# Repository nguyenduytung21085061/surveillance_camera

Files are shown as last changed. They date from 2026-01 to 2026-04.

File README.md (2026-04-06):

# 📷 Smart Home Surveillance Camera System

🇺🇸 English | 🇻🇳 [Vietnamese](README_vi.md)

---

## 📌 Project Status

This project is currently in the **research and development stage**.  
The goal is to develop a real product for **home use**, testing system stability, performance, and usability in real-world conditions.

---

## 🎯 Project Goal

Build a **low-cost smart home surveillance system** that can:

- Detect when someone stands in front of the house gate
- Notify family members inside the house in real time
- Run AI detection on an embedded device

In addition, the Camera Node is designed so it can be developed into an **independent smart door camera product**, which can:

- Be mounted in front of an apartment or house door
- Monitor visitors in real time
- Recognize whether the person is a family member or just detect unknown people
- Work as a standalone smart security device

---

## 🧱 System Architecture

The system is divided into **two main nodes**:

System Overview

---

## 1️⃣ Camera Node

Main task: Monitor the front gate and detect people.

### Hardware

- Embedded board: Luckfox Pico (RV1103G1)
- USB Camera
- USB WiFi dongle (mainly for SSH development)
- Real-time display screen

### Why Luckfox Pico?

- Powerful enough to run person detection models
- Small size, low power
- Suitable for edge AI applications

### Functions

- Capture video from USB camera
- Run AI model to detect people
- Display real-time video
- Send notification signal to Notice Node

---

## 2️⃣ Notice Node

Main task: Notify people inside the house.

### Hardware

- MCU: STM32F103RCT6
- Audio amplifier (I2S output)
- Speaker module
- Wireless communication module: HC-12

### Functions

- Receive signal from Camera Node
- Play voice/audio alert
- Can be placed in kitchen, bedroom, etc.

---

## 📡 Communication

Camera Node communicates with Notice Node using:

- HC-12 wireless serial module
- Low cost
- Long range
- Simple UART interface

---

## 🛠 Technologies Used

- Embedded Linux on Luckfox Pico
- STM32 HAL firmware (C language)
- UART wireless communication
- AI person detection model (YOLO / RKNN planned)

---

## 📅 Project Progress

| No | Task | Status | Completion Date |
|----|---|---|---|
| 1 | Read USB WiFi | ✅ Done | 24/01/2026 |
| 2 | Interface TFT display | ✅ Done | 25/01/2026 |
| 3 | Read USB camera | ✅ Done | 26/01/2026 |
| 4 | Stream USB camera on TFT | ✅ Done | 28/01/2026 |
| 5 | Add Mobile OpenCV on Luckfox Pico | ✅ Done | 29/01/2026 |
| 6 | Fit stream size from 160x120 → 160x128 on TFT | ✅ Done | 29/01/2026 |
| 7 | Run RKNN on Luckfox Pico | ✅ Done | 05/02/2026 |
| 8 | Load YOLOv5 model to detect person | ✅ Done | 07/02/2026 |
| 9 | Add confidence score on TFT | ✅ Done | 08/01/2026 |
|10 | Research USB hub expansion for Luckfox Pico | ✅ Done | 11/01/2026 |
|11 | Draw USB hub schematic for Camera Node | ✅ Done | 06/04/2026 |
|12 | Design PCB for Camera Node | ⏳ Pending | — |
|13 | Test STM32F103RCT6 board | ✅ Done | 15/01/2026 |
|14 | Test HC-12 communication between Luckfox Pico and STM32F103RCT6 | ✅ Done | 17/01/2026 |
|15 | Develop I2S audio with amplifier & speaker | ✅ Done| 22/02/2026 |
|16 | Full test: Person detection → Notice Node → Speaker alert | ⏳ Pending | — |
|17 | Research schematic for Notice Node | ⏳ Pending | — |
|18 | System evaluation testing | ⏳ Pending | — |
|19 | Upgrade TFT screen to larger display | ✅ Done | 03/04/2026 |
|20 | Research face embedding on Luckfox Pico | ⏳ Pending | — |
|21 | Develop standalone Camera Node product | ⏳ Pending | — |
|22 | Research mobile monitoring communication system | ⏳ Pending | — |

---

## 👨‍💻 Author

Nguyễn Duy Tùng  
Embedded Systems & IoT Developer  

---

⭐ If you like this project, please give it a star!

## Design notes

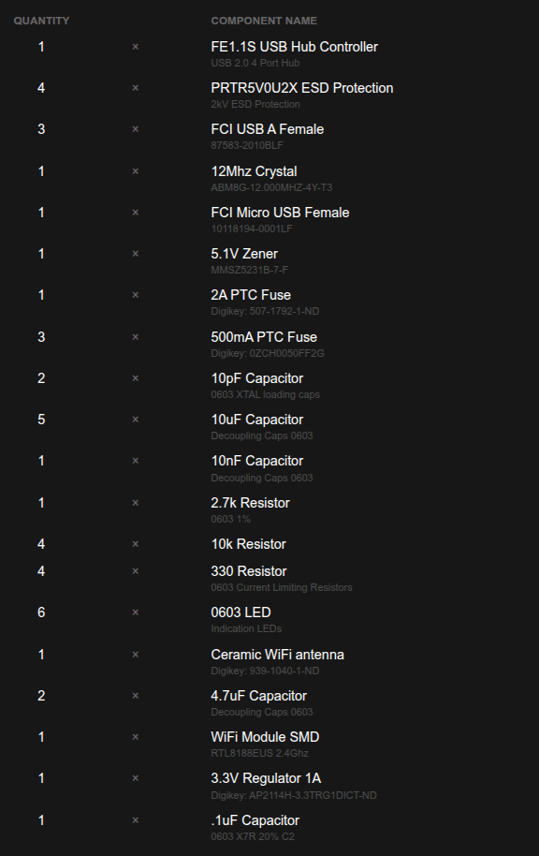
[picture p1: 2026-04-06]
schematics/doc/Screenshot from 2026-04-05 21-27-36.png

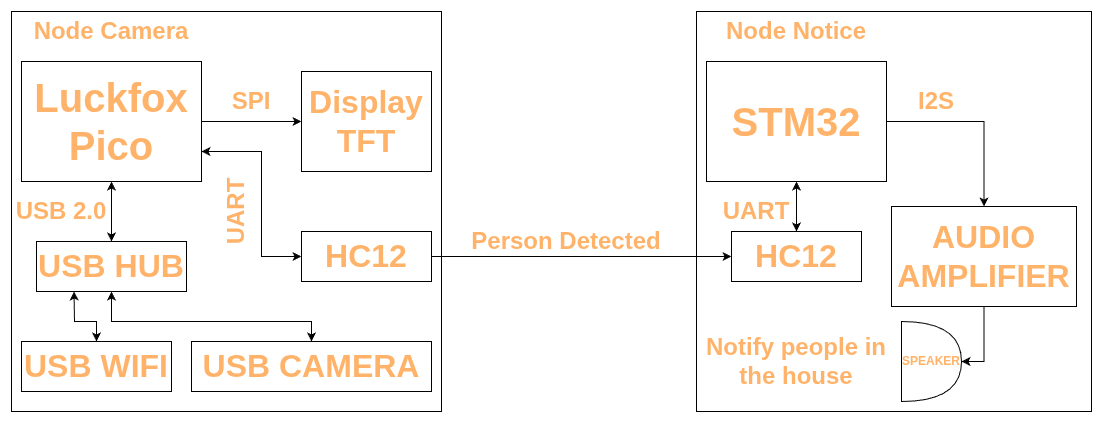
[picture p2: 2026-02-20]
photo/details_system.png

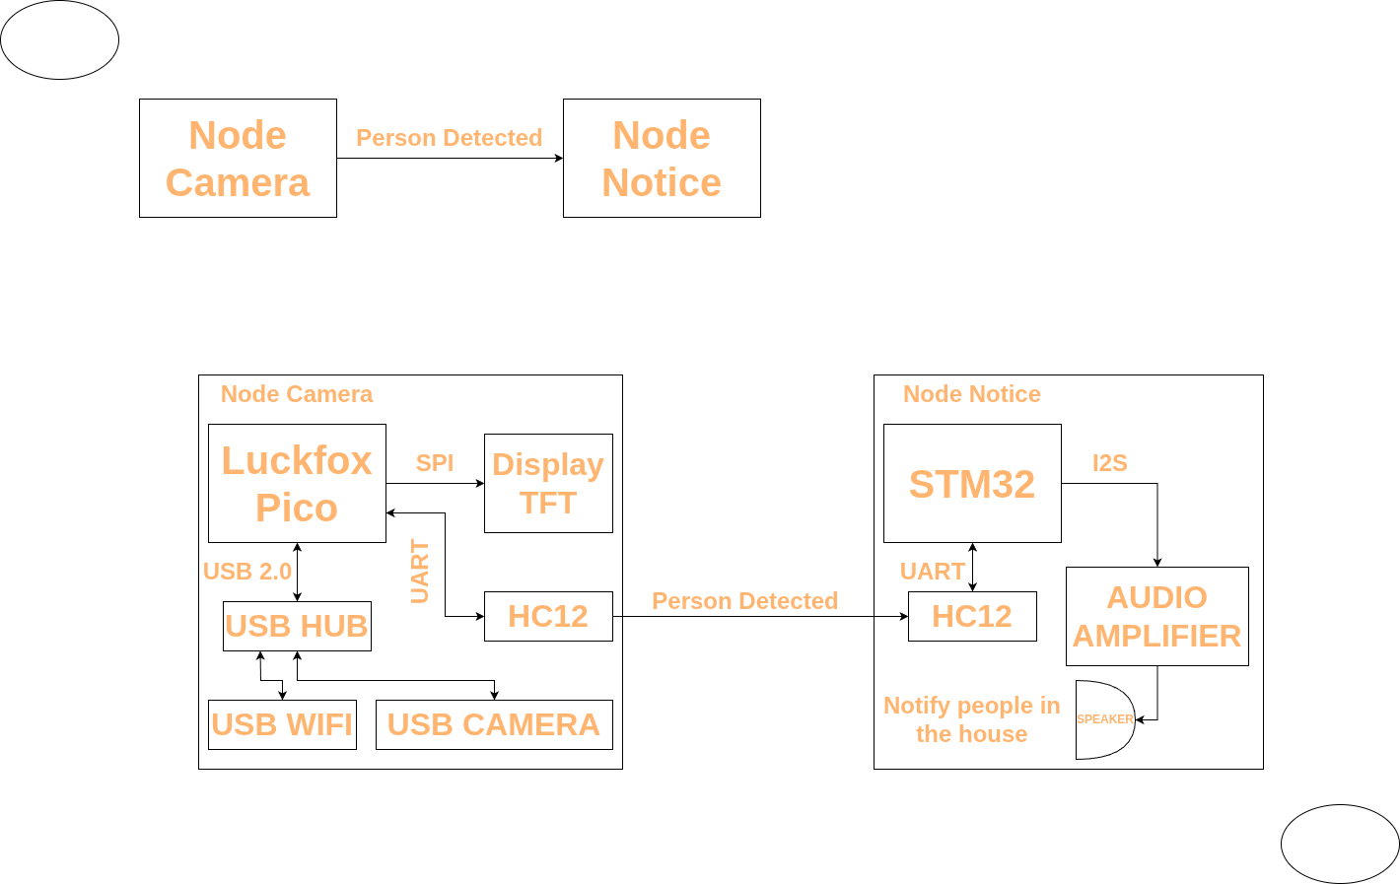
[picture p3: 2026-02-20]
diagram/system.png

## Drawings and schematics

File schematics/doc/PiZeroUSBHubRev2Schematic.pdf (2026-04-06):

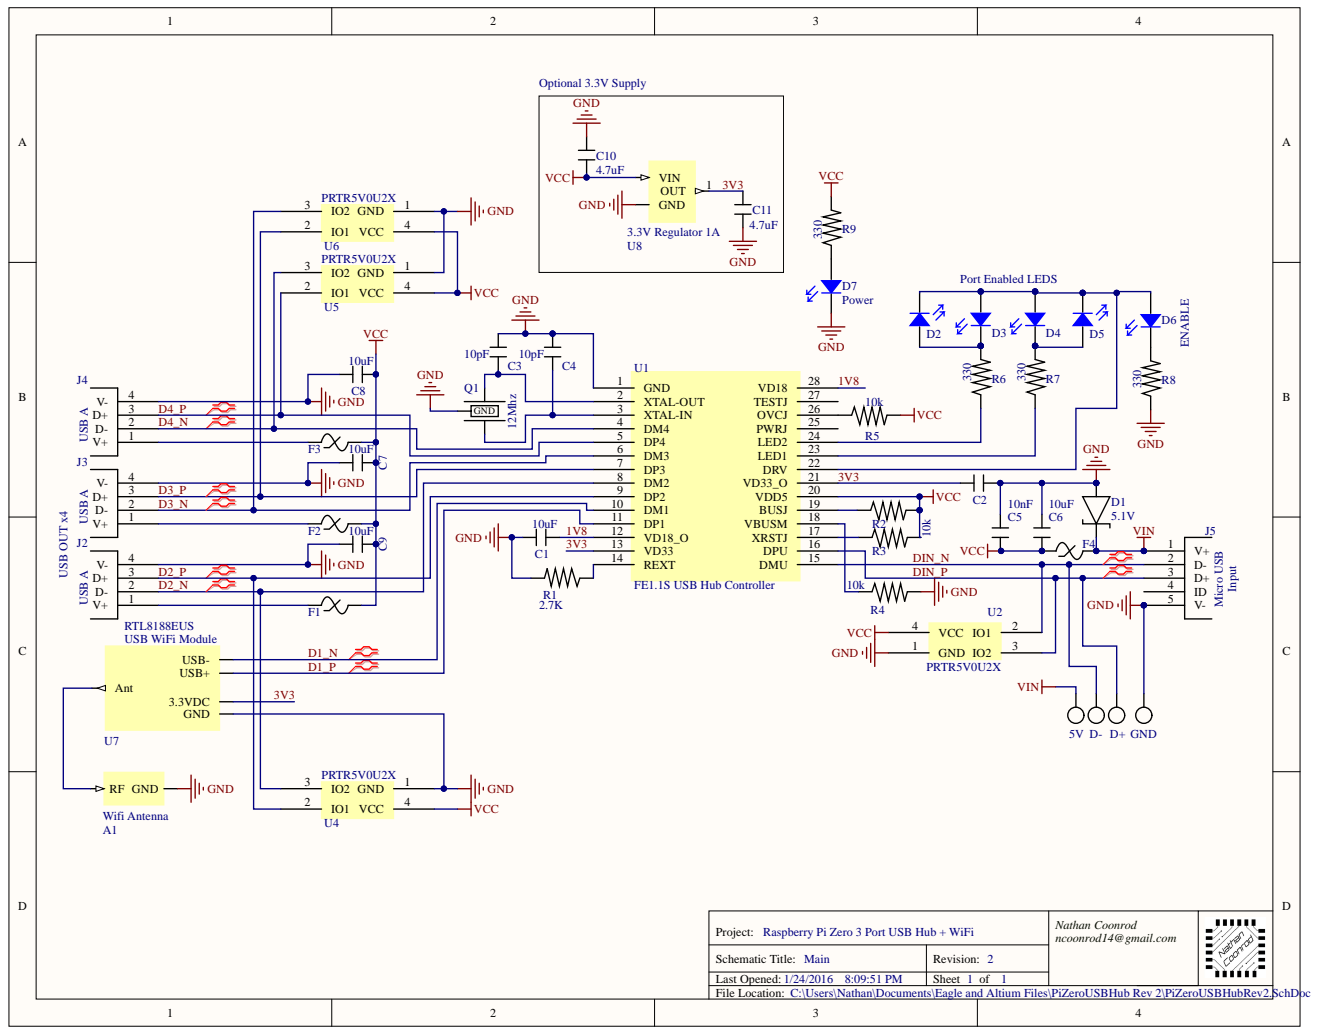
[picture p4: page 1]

Project: Raspberry Pi Zero 3 Port USB Hub + WiFi | Nathan Coonrod ncoonrod14@gmail.com

Schematic Title: Main | Revision: 2
Last Opened: 1/24/2016 8:09:51 PM | Sheet 1 of 1

C:\Users\Nathan\Documents\Eagle and Altium Files\PiZeroUSBHub Rev 2\PiZeroUSBHubRev2.SchDoc

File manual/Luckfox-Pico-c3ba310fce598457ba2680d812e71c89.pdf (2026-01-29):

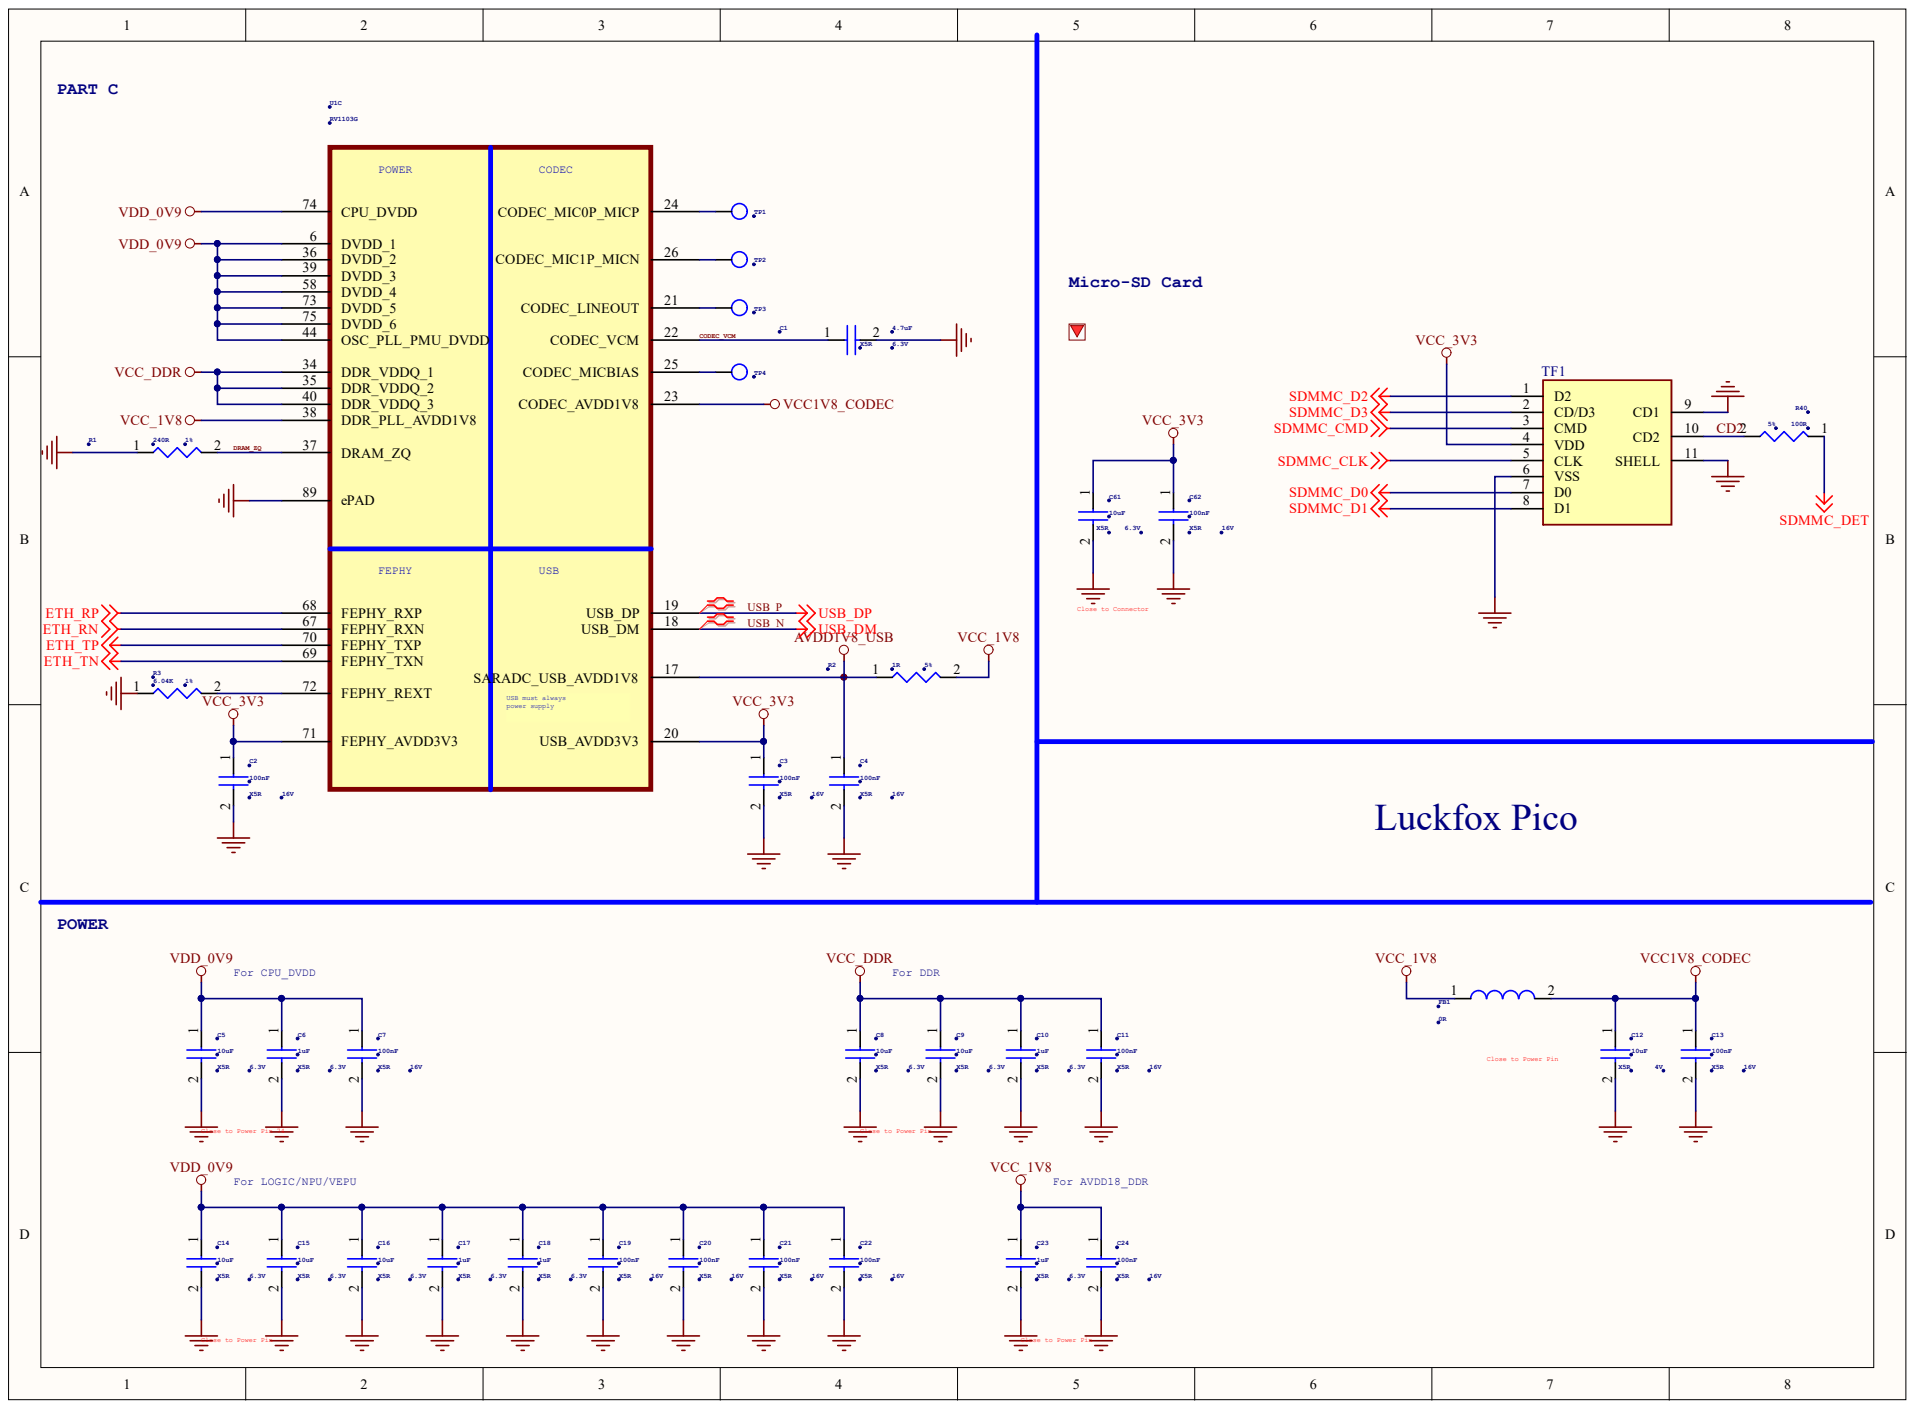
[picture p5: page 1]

Close to Power Pin

Close to Power Pin 74

For LOGIC/NPU/VEPU

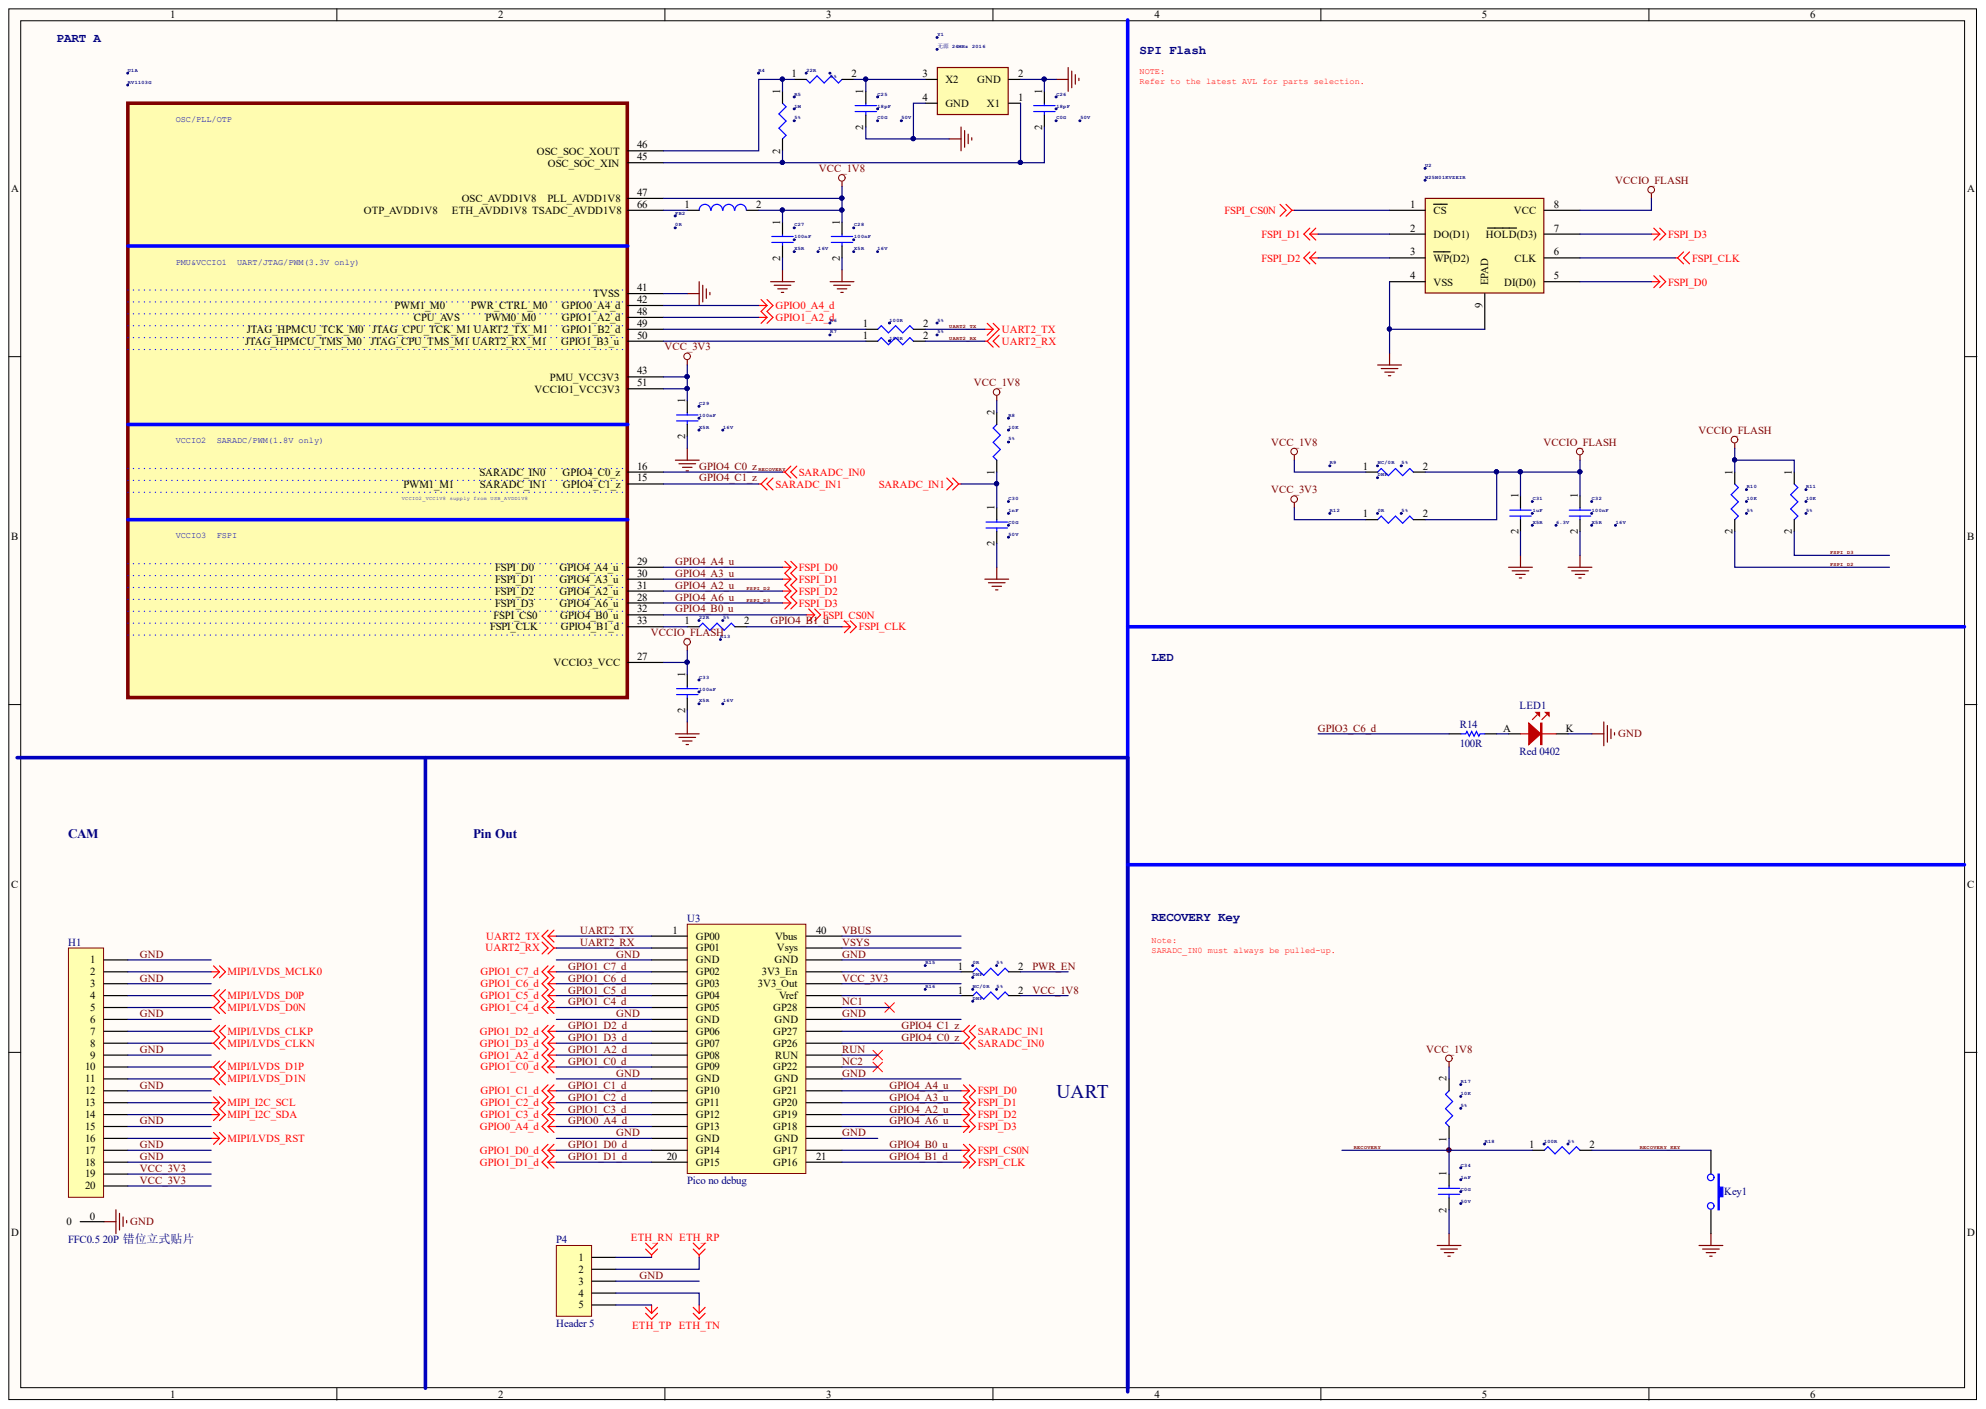
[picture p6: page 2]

NOTE:
Refer to the latest AVL for parts selection.

Note:
SARADC_IN0 must always be pulled-up.

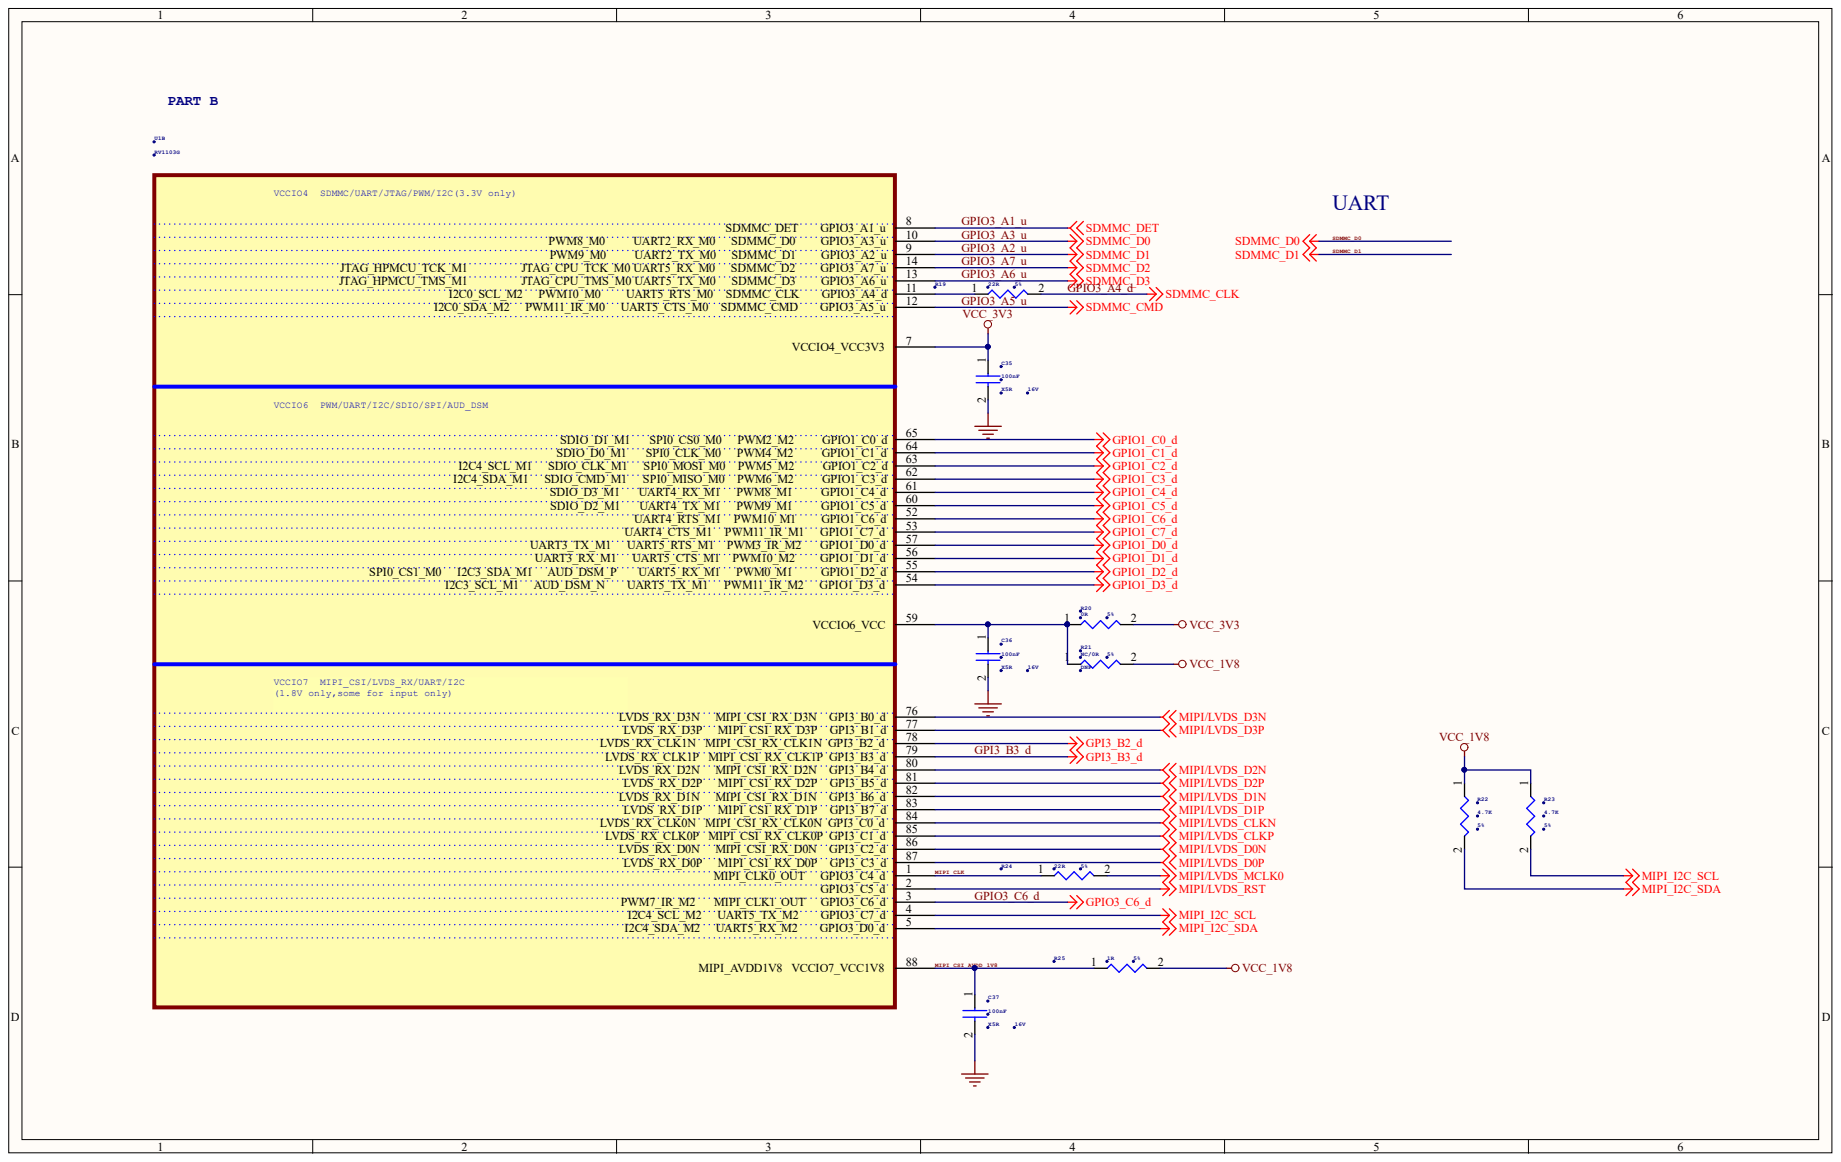
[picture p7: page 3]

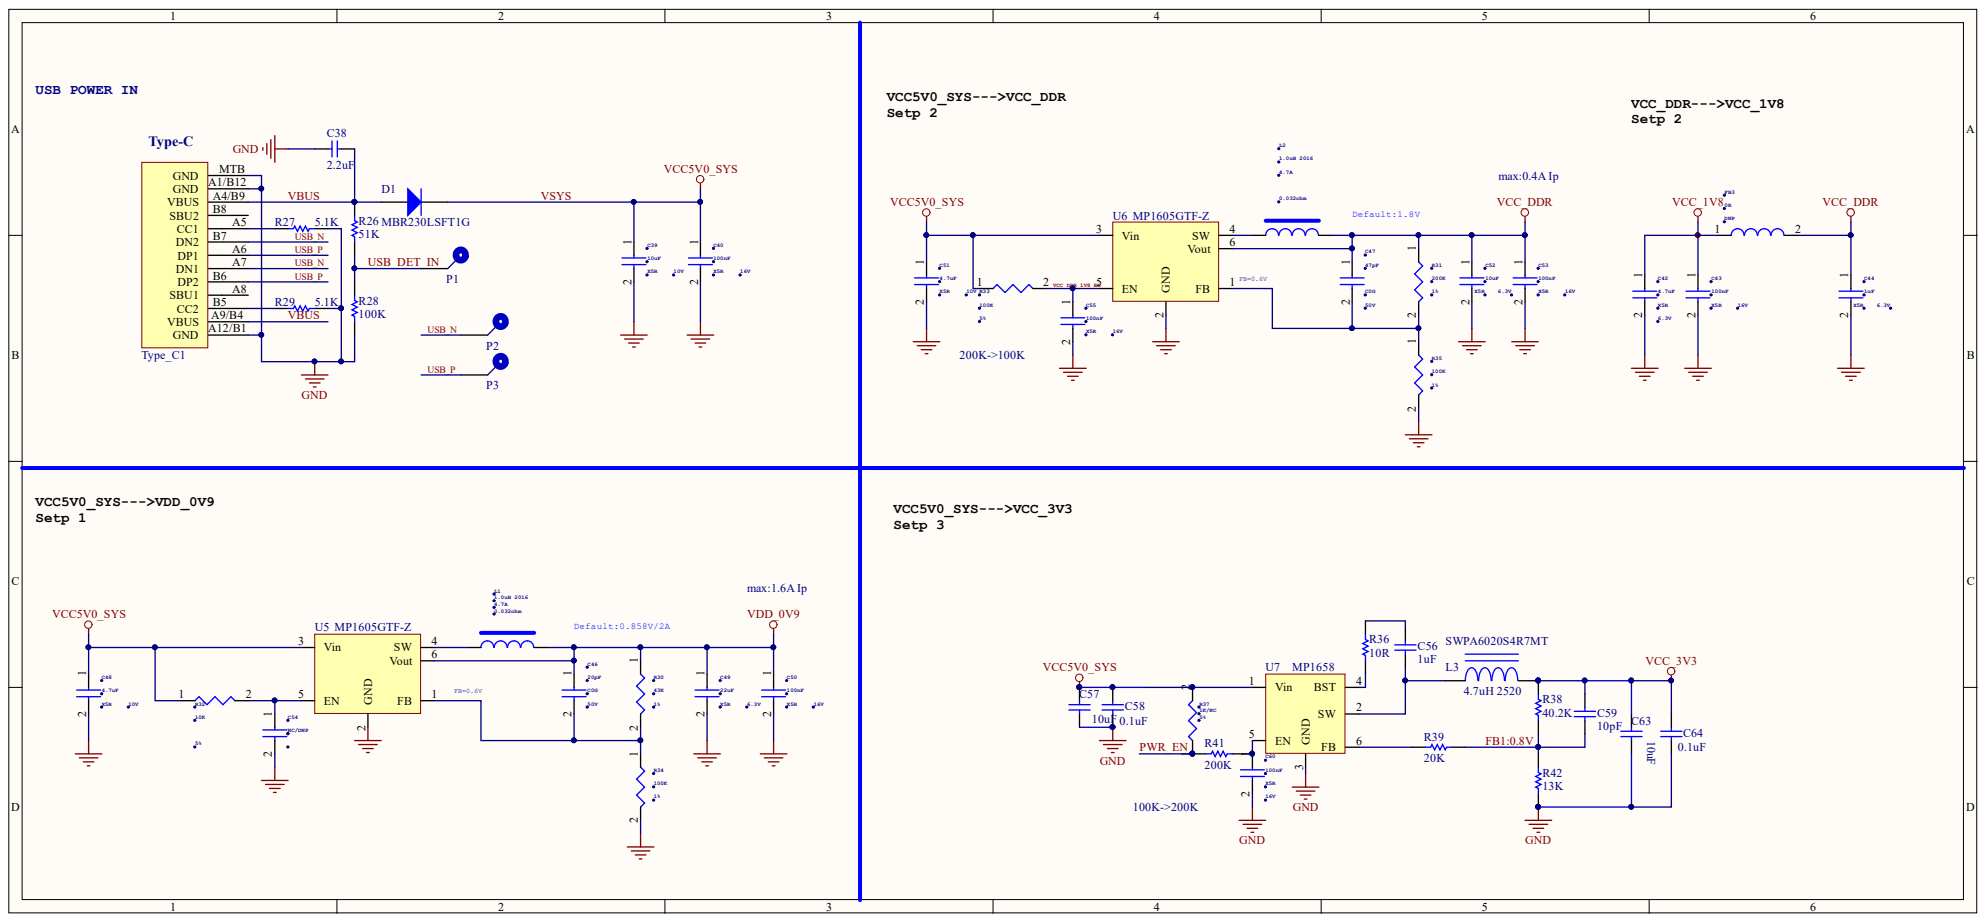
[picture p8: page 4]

VCC5V0_SYS--->VCC_DDR VCC_DDR--->VCC_1V8 Setp 2 L2 1.0uH 2016 4.7A max:0.4A Ip VCC5V0_SYS 0.032ohm VCC_DDR U6 MP1605GTF-Z

VCC5V0_SYS--->VDD_0V9 max:1.6A Ip L1 1.0uH 2016 4.7A VCC5V0_SYS 0.032ohm VDD_0V9 Default:0.858V/2A U5 MP1605GTF-Z | C56

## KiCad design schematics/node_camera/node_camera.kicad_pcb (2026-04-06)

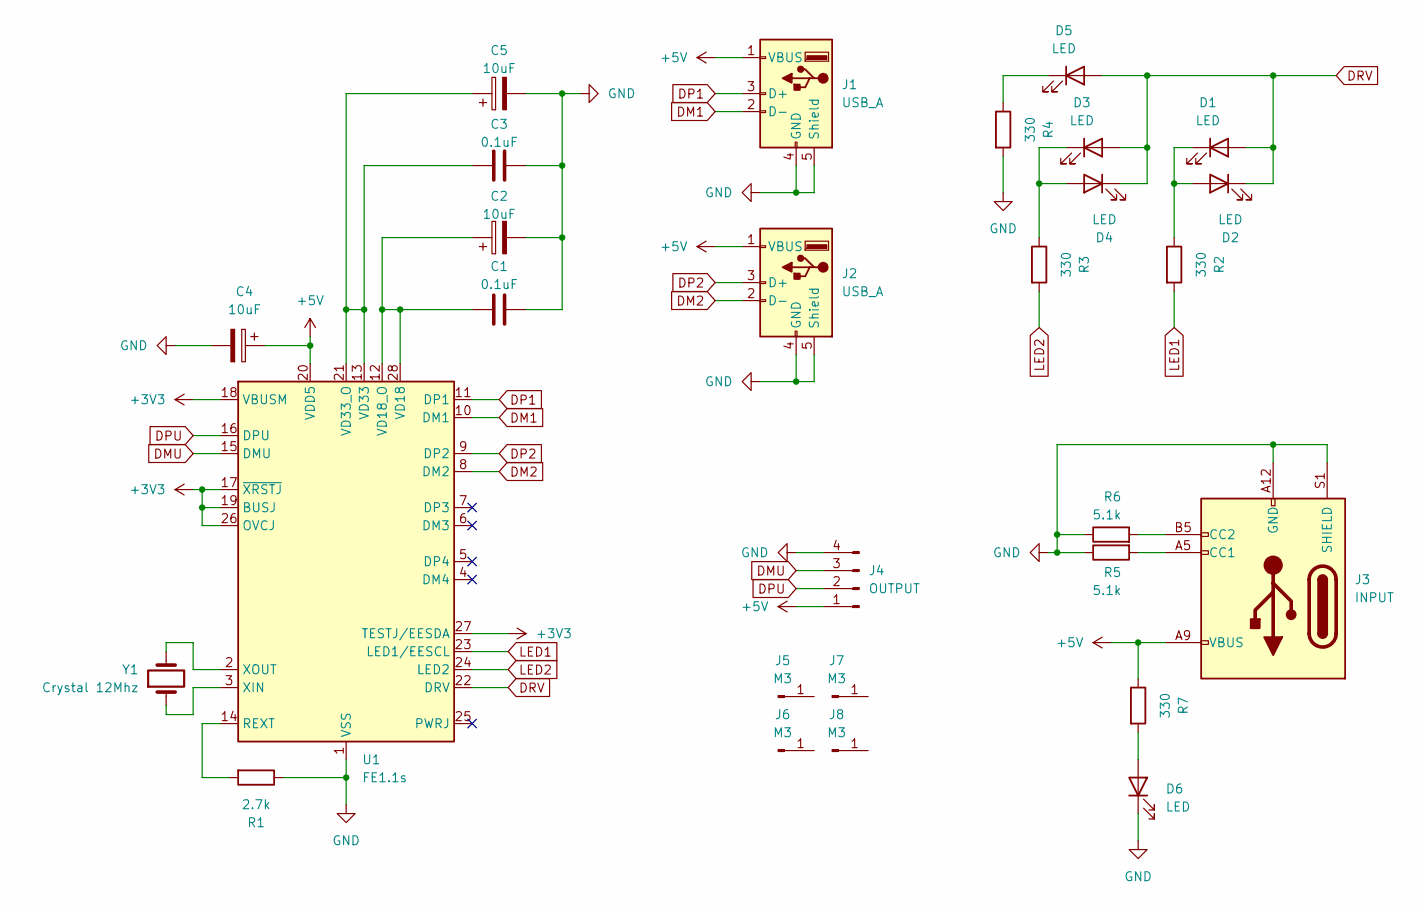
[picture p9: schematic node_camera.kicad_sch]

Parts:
C1, C3: 0.1uF; C_Disc_D3.0mm_W1.6mm_P2.50mm
C2, C4, C5: 10uF; CP_Radial_D4.0mm_P2.00mm
D1, D2, D3, D4, D5, D6: LED; LED_D3.0mm
J1, J2: USB_A; USB_A_Stewart_SS-52100-001_Horizontal
J3: INPUT; USB_C_Receptacle_GCT_USB4125-xx-x-0190_6P_TopMnt_Horizontal
J4: OUTPUT; PinSocket_1x04_P2.54mm_Vertical
J5, J6, J7, J8: M3; MountingHole_3.2mm_M3_Pad_Via
R1: 2.7k; R_Axial_DIN0207_L6.3mm_D2.5mm_P7.62mm_Horizontal
R2, R3, R4, R7: 330; R_Axial_DIN0207_L6.3mm_D2.5mm_P7.62mm_Horizontal
R5, R6: 5.1k; R_Axial_DIN0207_L6.3mm_D2.5mm_P7.62mm_Horizontal
U1: FE1.1s; SSOP-28_3.9x9.9mm_P0.635mm
Y1: Crystal 12Mhz; Crystal_HC49-4H_Vertical

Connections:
+3V3: U1.17 (~XRSTJ), U1.18 (VBUSM), U1.19 (BUSJ), U1.26 (OVCJ), U1.27 (TESTJ/EESDA)
+5V: C4.1, J1.1 (VBUS), J2.1 (VBUS), J3.A9 (VBUS), J3.B9 (VBUS), J4.1, R7.1, U1.20 (VDD5)
DM1: J1.2 (D-), U1.10 (DM1)
DM2: J2.2 (D-), U1.8 (DM2)
DMU: J4.3, U1.15 (DMU)
DP1: J1.3 (D+), U1.11 (DP1)
DP2: J2.3 (D+), U1.9 (DP2)
DPU: J4.2, U1.16 (DPU)
DRV: D1.2 (A), D2.1 (K), D3.2 (A), D4.1 (K), D5.2 (A), U1.22 (DRV)
GND: C1.2, C2.2, C3.2, C4.2, C5.2, D6.1 (K), J1.4 (GND), J1.5 (Shield), J2.4 (GND), J2.5 (Shield), J3.A12 (GND), J3.B12 (GND), J3.S1 (SHIELD), J4.4, R1.1, R4.2, R5.1, R6.1, U1.1 (VSS)
LED1: R2.2, U1.23 (LED1/EESCL)
LED2: R3.2, U1.24 (LED2)
unnamed: D1.1 (K), D2.2 (A), R2.1
unnamed: D3.1 (K), D4.2 (A), R3.1
unnamed: D5.1 (K), R4.1
unnamed: D6.2 (A), R7.2
unnamed: J3.A5 (CC1), R5.2
unnamed: J3.B5 (CC2), R6.2
unnamed: R1.2, U1.14 (REXT)
unnamed: C1.1, C2.1, U1.12 (VD18_O), U1.28 (VD18)
unnamed: C3.1, C5.1, U1.13 (VD33), U1.21 (VD33_O)
unnamed: U1.3 (XIN), Y1.1
unnamed: U1.2 (XOUT), Y1.2

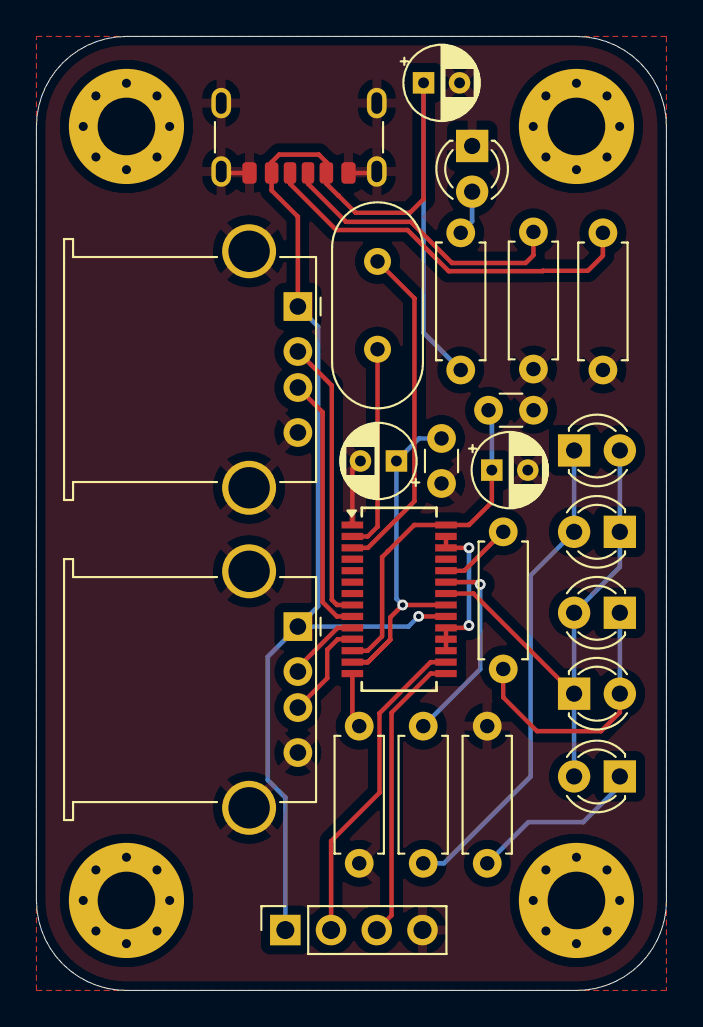
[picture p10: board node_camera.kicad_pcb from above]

Board: 2 copper layers, 35.0 x 53.0 mm, 28 parts (0 on the bottom side), 23 nets.

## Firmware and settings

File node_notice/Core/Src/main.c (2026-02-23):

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
/* Includes ------------------------------------------------------------------*/
#include "main.h"

/* USER CODE BEGIN Includes */
#include "stm32f1xx_hal.h"
#include "stm32f1xx_hal_gpio.h"
#include "stm32f1xx_ll_gpio.h"
#include <stdint.h>
#include <stdio.h>
#include <main.h>
#include "wav.h"
/* USER CODE END Includes */

I2S_HandleTypeDef hi2s2;

UART_HandleTypeDef huart1;
UART_HandleTypeDef huart2;

/* USER CODE BEGIN PV */
uint8_t rx2;
/* USER CODE END PV */

void SystemClock_Config(void);
static void MX_GPIO_Init(void);
static void MX_I2S2_Init(void);
static void MX_USART1_UART_Init(void);
static void MX_USART2_UART_Init(void);
/* USER CODE BEGIN 0 */
int _write(int fd, char *ptr, int len){
  HAL_StatusTypeDef hstatus;
  if(fd == 1 || fd == 2){
    hstatus = HAL_UART_Transmit(&huart1, (uint8_t*)ptr, len, HAL_MAX_DELAY);
    return (hstatus == HAL_OK) ? len : -1;
  }
  return -1;
}

void HAL_UART_RxCpltCallback(UART_HandleTypeDef *huart)
{
    if (huart->Instance == USART2){
        printf("HC12 RX: %c\r\n", rx2);
        HAL_UART_Receive_IT(&huart2, &rx2, 1);
    }
}
/* USER CODE END 0 */

/**
  * @brief  The application entry point.
  * @retval int
  */
int main(void)
{

  /* MCU Configuration--------------------------------------------------------*/

  /* Reset of all peripherals, Initializes the Flash interface and the Systick. */
  HAL_Init();

  /* Configure the system clock */
  SystemClock_Config();

  /* Initialize all configured peripherals */
  MX_GPIO_Init();
  MX_I2S2_Init();
  MX_USART1_UART_Init();
  MX_USART2_UART_Init();
  /* USER CODE BEGIN 2 */
  HAL_UART_Receive_IT(&huart2, &rx2, 1);
  LL_GPIO_IsOutputPinSet(GPIOC, LL_GPIO_PIN_7);
  printf("STM32F103RCT6\r\n");
  // for (int i = 0; i < 128; i++){
  //   /* code */
  //   if(HAL_I2C_IsDeviceReady(&hi2c2, (uint16_t)(i << 1),  3, 5) == HAL_OK)
  //     printf("%2X ", i);
  //   else
  //     printf("-- ");
  //   if(i > 0 && (i + 1) % 16 == 0)
  //     printf("\r\n");
  // }
  HAL_I2S_Transmit(&hi2s2, (uint16_t*)wav, wav_len / 2, HAL_MAX_DELAY);
  // HAL_UART_Transmit(&huart2, (uint8_t*)("Nguyenduytung\r\n"), 15, HAL_MAX_DELAY);
  /* USER CODE END 2 */

  /* Infinite loop */
  /* USER CODE BEGIN WHILE */
  while (1)
  {
    /* USER CODE END WHILE */

    /* USER CODE BEGIN 3 */
    LL_GPIO_TogglePin(GPIOC, LL_GPIO_PIN_7);
    HAL_Delay(2000);
  }
  /* USER CODE END 3 */
}

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


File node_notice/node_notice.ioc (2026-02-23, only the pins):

Mcu.UserName=STM32F103RCTx
PA10.Signal=USART1_RX
PA13.Signal=SYS_JTMS-SWDIO
PA14.Signal=SYS_JTCK-SWCLK
PA2.Signal=USART2_TX
PA3.Signal=USART2_RX
PA9.Signal=USART1_TX
PB12.Signal=I2S2_WS
PB13.Signal=I2S2_CK
PB15.Signal=I2S2_SD
PC7.Signal=GPIO_Output
PD0-OSC_IN.Signal=RCC_OSC_IN
PD1-OSC_OUT.Signal=RCC_OSC_OUT

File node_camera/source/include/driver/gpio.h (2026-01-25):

#ifndef _GPIO_H_
#define _GPIO_H_

#include <fcntl.h>
#include <cstdio>
#include <unistd.h>
#include <cstring>

typedef enum {
    GPIO0_A4_D = 4,
    GPIO1_A2_D = 34,
    GPIO1_B2_D = 42,
    GPIO1_B3_D = 43,
    GPIO1_C0_D = 48,
    GPIO1_C1_D = 49,
    GPIO1_C2_D = 50,
    GPIO1_C3_D = 51,
    GPIO1_C4_D = 52,
    GPIO1_C5_D = 53,
    GPIO1_C6_D = 54,
    GPIO1_C7_D = 55,
    GPIO1_D0_D = 56,
    GPIO1_D1_D = 57,
    GPIO1_D2_D = 58,
    GPIO1_D3_D = 59,
    GPIO4_A2_D = 130,
    GPIO4_A3_D = 131,
    GPIO4_A4_D = 132,
    GPIO4_A6_D = 134,
    GPIO4_B0_D = 136,
    GPIO4_B1_D = 137,
    GPIO4_C0_Z = 144,
    GPIO4_C1_Z = 145,
} gpio_pin_t;

typedef enum {
    OUTPUT = 0,
    INPUT,
    INPUT_PULLUP,
    INPUT_PULLDOWN
} gpio_mode_t;

typedef enum {
    LOW = 0,
    HIGH 
} gpio_level_t;

class gpio{
    public:
        gpio();
        ~gpio();
        void init(gpio_pin_t pins, gpio_mode_t mode);
        void export_gpio();
        void unexport_gpio();
        void direction_gpio();
        void set_mode(gpio_mode_t mode);
        void set_level(gpio_level_t level);
        bool get_level();

    private:
        gpio_pin_t pins;
        gpio_mode_t mode;
};

#endif

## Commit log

2026-01-24 create node camera
2026-01-25 complited on gpio driver not test function
2026-01-25 driver spi on linux
2026-01-25 repair spi, gpio, st7735s
2026-01-25 turn oon printf is not debug
2026-01-29 add opencv-mobile on luckfox-pico
    [QFN-88_L9.0-W9.0-P0.35-TL-EP6.5.pcbdoc, RV1103G11_RV1103G1.schdoc]
2026-02-06 add library 3rdparty luckfox pico
2026-02-06 repair source yolov5 on luckfox pico
2026-02-06 repair source uitls on luckfox pico
2026-02-07 resource opencv mobile and rknn in luckfox pico
2026-02-07 success load model yolov5 rknn on luckfox pico
2026-02-07 remove frame timing and FPS limiting from main loop
2026-02-22 create project stm32 on node notice
2026-02-22 update time on project stm32 test amplifier
2026-02-22 test communication node camera and node node notice on hc12
2026-04-02 driver tft ili9341
2026-04-06 Draw schematic and PCB USB hub usb ic fe1.1s
    [node_camera.kicad_pcb, node_camera.kicad_sch]

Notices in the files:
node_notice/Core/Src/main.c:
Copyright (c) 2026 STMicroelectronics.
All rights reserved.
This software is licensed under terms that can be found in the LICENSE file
